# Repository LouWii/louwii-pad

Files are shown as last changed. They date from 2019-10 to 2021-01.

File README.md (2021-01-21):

# Louwii Pad

Very basic USB macro pad for tinkering and experimenting.

louwii-pad-rev1-small

## Bootloader Flashing

In case the ATmega32u4 comes without a bootloader flashed in, the board has an ICSP port to flash a bootloader. See [flashing an ATmega via ICSP on Sparkfun](https://learn.sparkfun.com/tutorials/installing-an-arduino-bootloader/all).

## Inspiration

* [ruiqimao's tutorial](https://github.com/ruiqimao/keyboard-pcb-guide)
* [Arisu](https://github.com/FateNozomi/arisu-pcb)
* [cpm43](https://github.com/Gtrx0/cpm43)
* [Gtrx0/Keyboard-template-atmega32u4](https://github.com/Gtrx0/Keyboard-template-atmega32u4)

[ATmega32u4 official doc](http://ww1.microchip.com/downloads/en/devicedoc/atmel-7766-8-bit-avr-atmega16u4-32u4_datasheet.pdf)

## BOM (list of components)

[See doc](BOM.md)

## Blank ATmega flashing (no bootloader flashed, fuses not set properly)

[See doc](ATMEGA.md)

## Firmware

[See doc](FIRMWARE.md)

## Revisions

[See doc](REVISIONS.md)

## Third party libs

[See doc](LIBS.md)

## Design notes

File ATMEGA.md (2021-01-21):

# ATmega flashing

Blank/virgin ATmega might be missing a few things in order to run properly as a macro pad with a QMK firmware.

## Setup

### ISP programmer and avrdude

The Louwii-pad exposes ISP pins of the ATmega in order to program it via an ISP programmer. You can use an Arduino as an ISP programmer ([see official doc](https://www.arduino.cc/en/tutorial/arduinoISP#toc2)), or buy a dedicated one like an USBasp ([see official page](https://www.fischl.de/usbasp/)).

There's no other way to program your ATmega32u4 if it came without a bootloader (in case of a Louwii-pad).

We're going to use the [avrdude](https://www.nongnu.org/avrdude/) command tool to set the fuses and flash the bootloader.

### ATmega Fuses

The fuses are used to set some parameters to the ATmega, defining how it runs. We need to set them according to our use.

* **Low:** 0xFF (we use an external 16Mhz resonator)
* **High:** 0xD9 (default flash size etc..., SPI enabled) -- Note: we could disable SPI once we're done, but it's nice to have them if we mess up
* **Extended:** 0xC0 (Brown-out set to 4.3V, Hardware boot enabled) -- Note: We might set the brown-out down to 3.5V, in case of a voltage drop: 0xC1

We're not touching the lock fuse, we don't need to. It should be set to 0xFF by default, allowing us to do anything we want.

[See more about fuses](https://eleccelerator.com/fusecalc/fusecalc.php?chip=atmega32u4&LOW=FF&HIGH=D9&EXTENDED=C0&LOCKBIT=FF)

### Bootloader

You can either use Atmel DFU bootloader or the QMK fork QMK DFU.

* [Atmel DFU link](https://www.microchip.com/wwwproducts/en/ATmega32U4#additional-features) - Go in the _Documents_ tab, scroll down to _Software Libraries/Firmware_ and download the bootloaders zip file. It contains `ATMega32U4-usbdevice_dfu-1_0_0.hex`, the bootloader ready to be flashed.
* [QMK DFU link](https://docs.qmk.fm/#/flashing?id=qmk-dfu) - QMK DFU contains some customizations compared to the Atmel DFU that cam be handy, but we're not using them really. It can be generated via `make` commands in the QMK repo: `make planck/rev4:default:bootloader`

## Steps

### 1. Check that the ATmega is detected

To see if your programmer detects the ATmega, run

```
sudo avrdude -c usbasp-clone -p m32u4
```

Remove `sudo` if you're running the command in Windows.

In my case, I'm using a usbasp clone (`usbasp-clone`). But you can change it to `usbasp` or `arduino` or any other programmer you use.

This should give you something like this

```
$ sudo avrdude -c usbasp-clone -p m32u4

avrdude: warning: cannot set sck period. please check for usbasp firmware update.
avrdude: AVR device initialized and ready to accept instructions

Reading | ################################################## | 100% 0.00s

avrdude: Device signature = 0x1e9587 (probably m32u4)

avrdude: safemode: Fuses OK (E:FF, H:D9, L:C0)

avrdude done.  Thank you.
```

If your fuses are different, that's fine, we're going to set them up properly.

### 2. Set the fuses

```
sudo avrdude -c usbasp-clone -p m32u4 -U lfuse:w:0xFF:m -U hfuse:w:0xD9:m -U efuse:w:0xC0:m
```

If you were not using the 16Mhz quartz yet, unplug the board and solder it in, the ATmega is now set to use it.

### 3. Flash the bootloader

```
sudo avrdude -c usbasp-clone -p m32u4 -U flash:w:ATMega32U4-usbdevice_dfu-1_0_0.hex
```

Once the bootloader is flashed, the ATmega will boot up in bootloader mode, ready to flash a program on it.

## The external resonator problem

```
device signature = 0x000000
device signature always changing
avrdude: initialization failed, rc=-1
```

When I received my ATmega chips, the fuses were set in such a way that the ATmega was expecting a "low speed" external resonator to be set on the XTAL1 pin. That's a hard to track problem: the ATmega wasn't responding when trying to be contacted via the SPI pins, and there's no way to know or change the fuses. After many hours of research, trial and error, I found 1 solution that worked: generating an approximate 8Mhz square wave signal via an Arduino.

What I did was: removing the 16Mhz quartz from the PCB. Connect the pin 9 or my Arduino Leonardo to the XTAL1 pin of the ATmega32u4 (the one on the left side on X1). Power on the Arduino. Connect the ATmega to the programmer. Run the test command, cross fingers. And the ATmega showed up.

The arduino program:

```
#ifdef __AVR_ATmega2560__
  const byte CLOCKOUT = 11;  // Mega 2560
#else
  const byte CLOCKOUT = 9;   // Uno, Duemilanove, etc.
#endif

void setup ()
{
  // set up 8 MHz timer on CLOCKOUT (OC1A)
  pinMode (CLOCKOUT, OUTPUT);
  // set up Timer 1
  TCCR1A = bit (COM1A0);  // toggle OC1A on Compare Match
  TCCR1B = bit (WGM12) | bit (CS10);   // CTC, no prescaling
  OCR1A =  0;       // output every cycle
}

void loop ()
{
  // whatever
}
```

The ATmega can also use its internal clock, so depending on how its fuses were set (specifically the `LOW` fuse), it might be able to respond to the avrdude command without any resonator soldered in. Boy, this ain't easy.

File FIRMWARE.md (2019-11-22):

# Firmware

I'm using [QMK](https://qmk.fm/), it's a keyboard firmware framework but has a ton of features, making it super easy to implement features for louwii-pad, including OLED screen, rotary encoders, RGB lights etc...

The firmware is in a separate repository: [LouWii/qmk_firmware](https://github.com/LouWii/qmk_firmware/tree/louwii-pad), branch `louwii-pad`

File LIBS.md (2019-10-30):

# Libs & other third party elements

Rotary encoder 3D model from [Alps](https://www.alps.com/prod/info/E/HTML/Encoder/Incremental/EC11/EC11_list.html). Modified  in FreeCAD because that pink color was hurting my eyes.

OLED screen 3D model from [GrabCAD](https://grabcad.com/library/oled-display-128x32-1)

Took a few footprints from [keyboard_parts.pretty](https://github.com/colemarkham/keyboard_parts.pretty)

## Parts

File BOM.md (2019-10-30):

# BOM (components list)

I tried to use widely available components to make it as affordable as possible and accessible. No fancy connector made by 1 manufacturer only (well, the only exception to this is the ATmega32u4, but it's one of the best chip for this use, I don't think it's going to be ended soon). That hopefully means we should still be able to find the components in years to come.

| ref | components | quantity | packaging | notes | links |
| --- | --- | --- | --- | --- | --- |
| U1 | ATmega32u4 | 1 | TQFP44 | sometimes called ATmega32u4-AU | [LCSC](https://lcsc.com/product-detail/ATMEL-AVR_ATMEL_ATMEGA32U4-AU_ATMEGA32U4-AU_C44854.html) |
| X1 | Crystal 16Mhz | 1 | HC49-US | 20ppm or 30ppm | [LCSC](https://lcsc.com/product-detail/DIP-Crystal-Resonators_Yangxing-Tech-X49SD16MSD2SC_C16212.html) |
| SW1 | Tactile switch 5.2x5.2mm | 1 | | SMD switch | [LCSC](https://lcsc.com/product-detail/Tactile-Switches_Korean-Hroparts-Elec-K2-1187SQ-D4SW-06_C223821.html) |
| J1 | Mini USB B connector | 1 | | | [LCSC](https://lcsc.com/product-detail/USB-Connectors_Jing-Extension-of-the-Electronic-Co-C69074_C69074.html) |
| J2 | 2x3 header pin | 1 | | 2.54mm pitch; optional component | [LCSC](https://lcsc.com/product-detail/Pin-Header-Female-Header_Boom-Precision-Elec-C65114_C65114.html) |
| RSW1 | rotary encoder switch | 1 | EC11E or EC12E | With momentary switch built-in | |
| RSW2 - 6 | rotary encoder | 5 | EC11E or EC12E | | |
| RGB1 - 4 | WS2812B | 4 | | RGB LED SMD | [LCSC](https://lcsc.com/product-detail/Light-Emitting-Diodes-LED_Worldsemi-WS2812B-B_C114586.html) |
| D1 - 8 | diode 1N4148 | 8 | DO-35 | | [LCSC](https://lcsc.com/product-detail/Switching-Diode_Semtech-1N4148_C14516.html) |
| R1, R2 | resistor 10k | 2 | DIN0204 or DIN 0207 | 1/4W or 1/6W, metal film | [LCSC](https://lcsc.com/product-detail/Metal-Film-Resistor-TH_TA-I-Tech-RN16T21002F_C172508.html) |
| R3, R4 | resistor 22 | 2 | DIN0204 or DIN 0207 | 1/4W or 1/6W, metal film | [LCSC](https://lcsc.com/product-detail/Metal-Film-Resistor-TH_Chian-Chia-Elec-MF1-4W-22%CE%A9-1-T52_C119288.html) |
| R5, R6 | resistor 4.7k | 2 | DIN0204 or DIN 0207 | 1/4W or 1/6W, metal film | [LCSC](https://lcsc.com/product-detail/Metal-Film-Resistor-TH_Uniroyal-Elec-MFR0W4F4701A50_C57204.html) |
| C1, C2 | capacitor 22pF | 2 | ceramic leaded | 10%, 5mm pitch for cheapest | [LCSC](https://lcsc.com/product-detail/Multilayer-Ceramic-Capacitors-MLCC-Leaded_Dersonic-CD1H220JC9BECHD000_C263190.html) |
| C3 | capacitor 1uF | 1 | ceramic leaded | 10%, 5mm pitch for cheapest | [LCSC](https://lcsc.com/product-detail/Multilayer-Ceramic-Capacitors-MLCC-Leaded_Dersonic-CD1H105KC9IER1E000_C263187.html) |
| C4 - C7  | capacitor 0.1uF | 4 | ceramic leaded | (=100nF), 10%, 5mm pitch for cheapest | [LCSC](https://lcsc.com/product-detail/Multilayer-Ceramic-Capacitors-MLCC-Leaded_Dersonic-CD1H104KC94ER1E000_C263182.html) |
| C8 | capacitor 4.7uF | 1 | radial leaded | lead spacing 2mm | [LCSC](https://lcsc.com/product-detail/Aluminum-Electrolytic-Capacitors-Leaded_Rubycon-50YXF4R7MEFC5X11_C88759.html) |
| K1 - 8 | mechanical switch | 8 | | MX cherry compatible mechanical keyboard switches | |

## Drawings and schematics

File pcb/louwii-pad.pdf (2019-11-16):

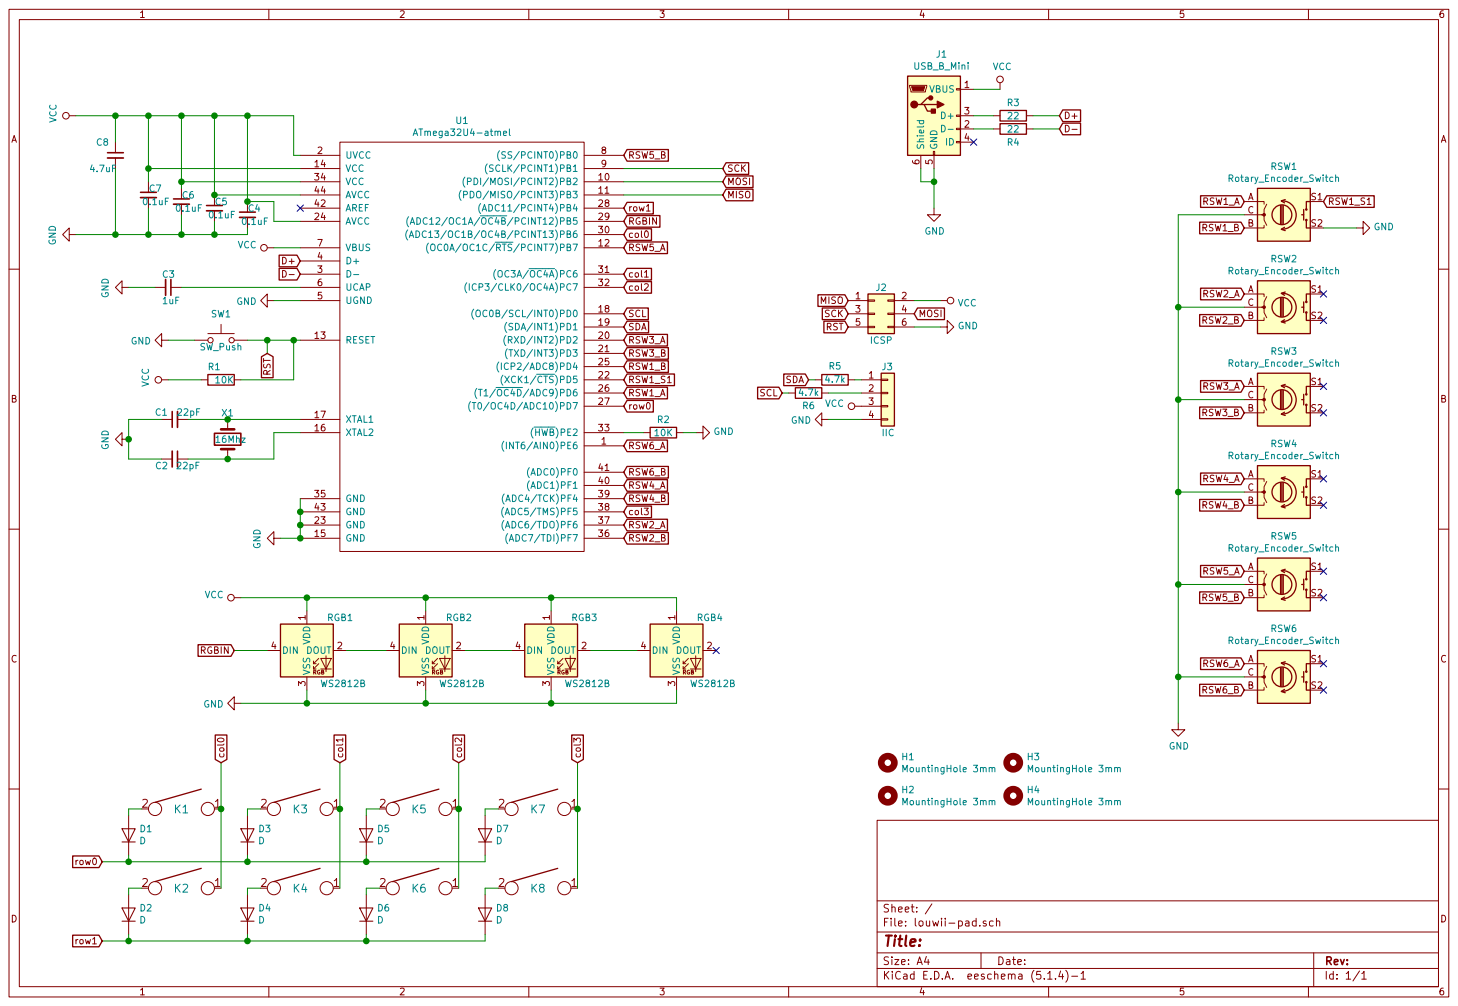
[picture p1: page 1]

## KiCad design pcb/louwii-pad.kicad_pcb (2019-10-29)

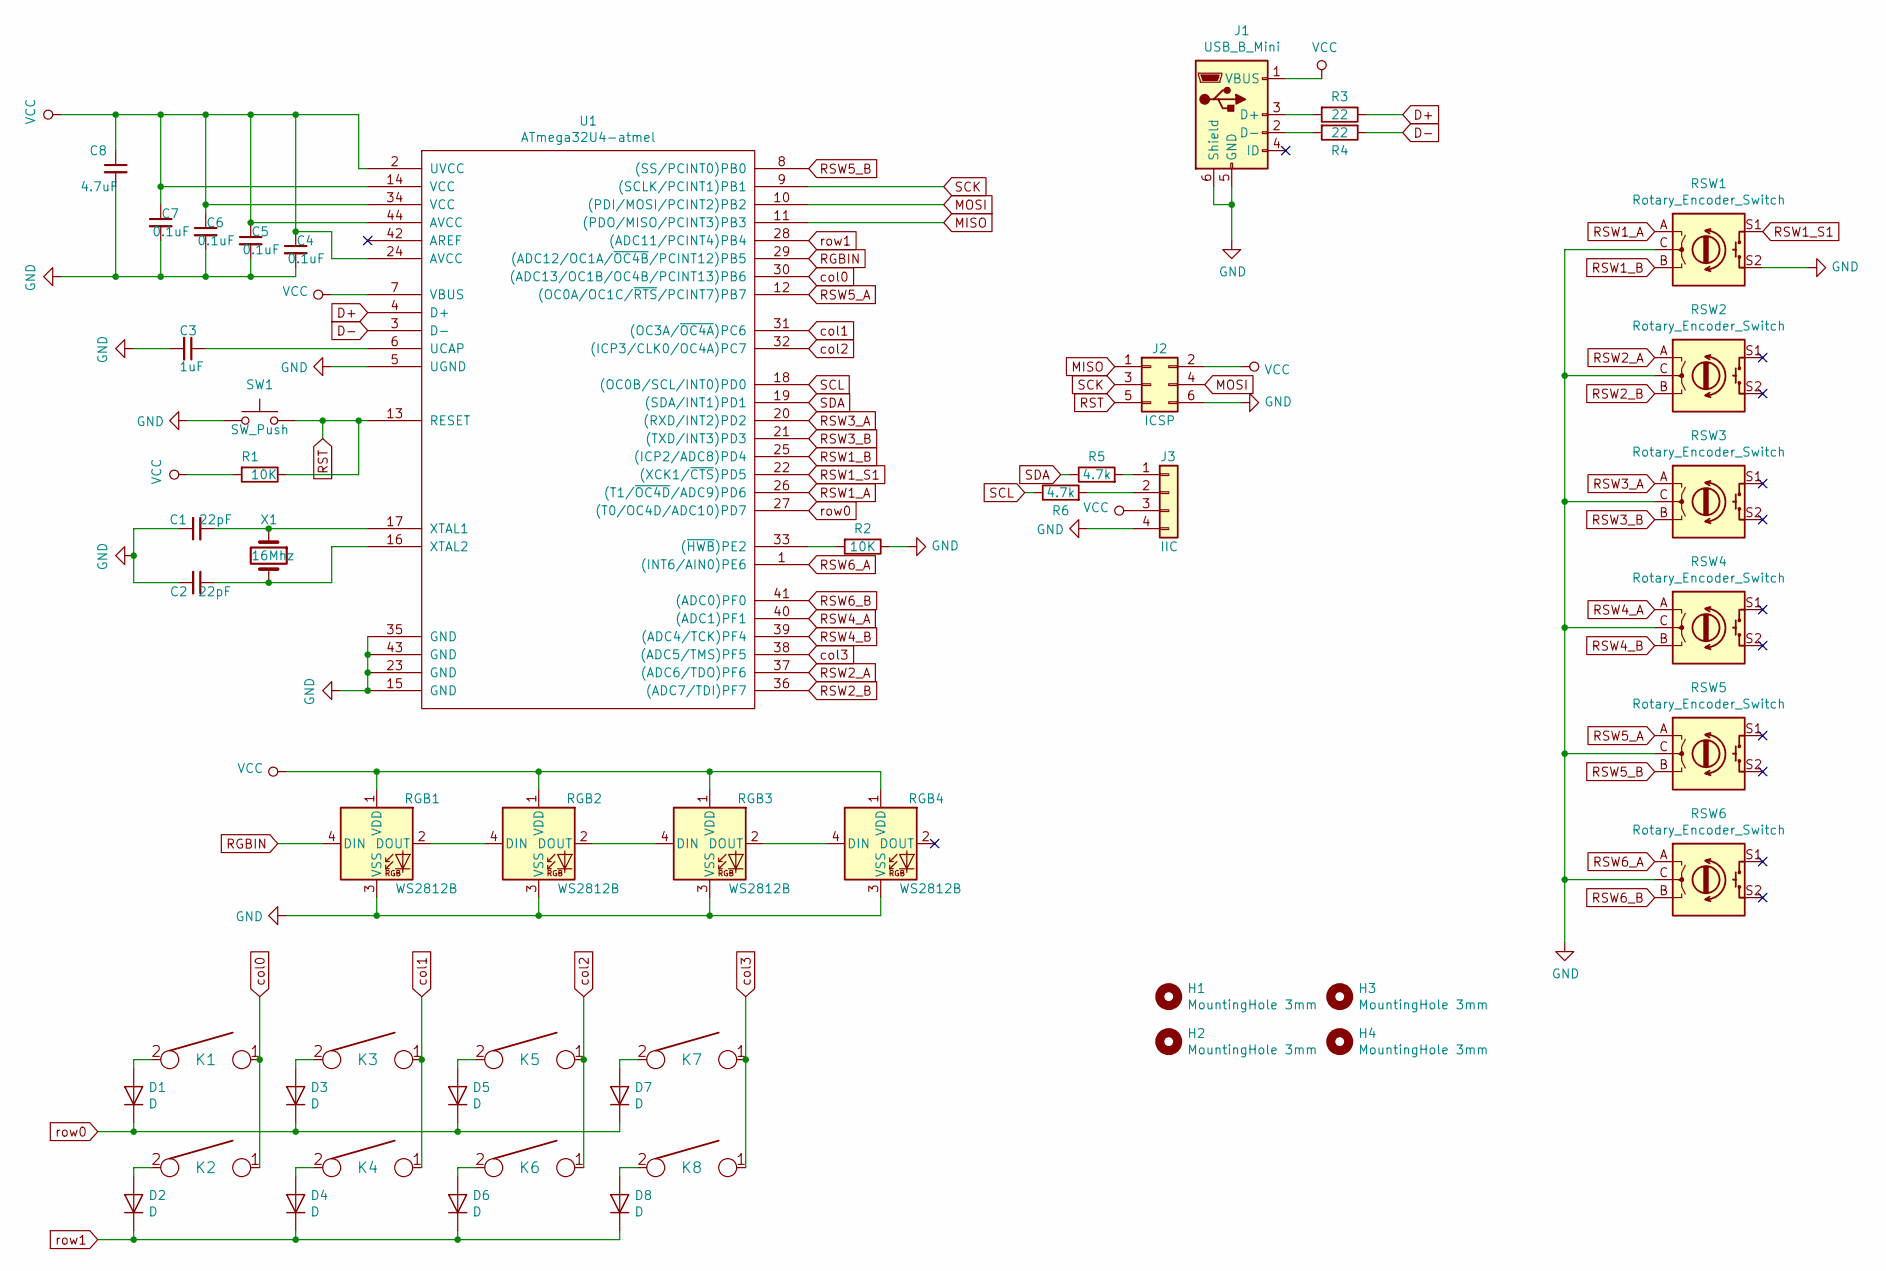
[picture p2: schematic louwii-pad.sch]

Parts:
C1, C2: 22pF; C_Disc_D4.3mm_W1.9mm_P5.00mm
C3: 1uF; C_Disc_D4.3mm_W1.9mm_P5.00mm
C4, C5, C6, C7: 0.1uF; C_Disc_D4.3mm_W1.9mm_P5.00mm
C8: 4.7uF; C_Radial_D5.0mm_H7.0mm_P2.00mm
D1, D2, D3, D4, D5, D6, D7, D8: D; D_DO-35_SOD27_P7.62mm_Horizontal
H1, H2, H3, H4: MountingHole 3mm; MountingHole_3.2mm_M3_ISO7380_Pad
J1: USB_B_Mini; USB_Mini-B_Lumberg_2486_01_Horizontal
J2: ICSP; PinHeader_2x03_P2.54mm_Vertical
J3: IIC; PinHeader_1x04_P2.54mm_Vertical
K1, K2, K3, K4, K5, K6, K7, K8: KEYSW; MX_PCB_100H
R1, R2: 10K; R_Axial_DIN0207_L6.3mm_D2.5mm_P10.16mm_Horizontal
R3, R4: 22; R_Axial_DIN0207_L6.3mm_D2.5mm_P10.16mm_Horizontal
R5, R6: 4.7k; R_Axial_DIN0207_L6.3mm_D2.5mm_P10.16mm_Horizontal
RGB1, RGB2, RGB3, RGB4: WS2812B; WS2812b
RSW1, RSW2, RSW3, RSW4, RSW5, RSW6: Rotary_Encoder_Switch; RotaryEncoder_Alps_EC11E-Switch_Vertical_H20mm
SW1: SW_Push; SW_SPST_TL3342
U1: ATmega32U4-atmel; TQFP-44_10x10mm_P0.8mm
X1: 16Mhz; Crystal_HC49-U_Vertical

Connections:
D+: R3.1, U1.4 (D+)
D-: R4.1, U1.3 (D-)
GND: C1.1, C2.2, C3.2, C4.2, C5.2, C6.2, C7.2, C8.2, J1.5 (GND), J1.6 (Shield), J2.6, J3.4, R2.1, RGB1.3 (VSS), RGB2.3 (VSS), RGB3.3 (VSS), RGB4.3 (VSS), RSW1.C, RSW1.S2, RSW2.C, RSW3.C, RSW4.C, RSW5.C, RSW6.C, SW1.1, U1.5 (UGND), U1.15 (GND), U1.23 (GND), U1.35 (GND), U1.43 (GND)
MISO: J2.1, U1.11 ((PDO/MISO/PCINT3)PB3)
MOSI: J2.4, U1.10 ((PDI/MOSI/PCINT2)PB2)
unnamed: C1.2, U1.17 (XTAL1), X1.1
unnamed: C2.1, U1.16 (XTAL2), X1.2
unnamed: C3.1, U1.6 (UCAP)
unnamed: D1.2 (A), K1.2
unnamed: D2.2 (A), K2.2
unnamed: D3.2 (A), K3.2
unnamed: D4.2 (A), K4.2
unnamed: D5.2 (A), K5.2
unnamed: D6.2 (A), K6.2
unnamed: D7.2 (A), K7.2
unnamed: D8.2 (A), K8.2
unnamed: J1.2 (D-), R4.2
unnamed: J1.3 (D+), R3.2
unnamed: J3.1, R5.2
unnamed: J3.2, R6.2
unnamed: R2.2, U1.33 ((~HWB~)PE2)
unnamed: RGB1.2 (DOUT), RGB2.4 (DIN)
unnamed: RGB2.2 (DOUT), RGB3.4 (DIN)
unnamed: RGB3.2 (DOUT), RGB4.4 (DIN)
RGBIN: RGB1.4 (DIN), U1.29 ((ADC12/OC1A/~OC4B~/PCINT12)PB5)
RST: J2.5, R1.1, SW1.2, U1.13 (RESET)
RSW1_A: RSW1.A, U1.26 ((T1/~OC4D~/ADC9)PD6)
RSW1_B: RSW1.B, U1.25 ((ICP2/ADC8)PD4)
RSW1_S1: RSW1.S1, U1.22 ((XCK1/~CTS~)PD5)
RSW2_A: RSW2.A, U1.37 ((ADC6/TDO)PF6)
RSW2_B: RSW2.B, U1.36 ((ADC7/TDI)PF7)
RSW3_A: RSW3.A, U1.20 ((RXD/INT2)PD2)
RSW3_B: RSW3.B, U1.21 ((TXD/INT3)PD3)
RSW4_A: RSW4.A, U1.40 ((ADC1)PF1)
RSW4_B: RSW4.B, U1.39 ((ADC4/TCK)PF4)
RSW5_A: RSW5.A, U1.12 ((OC0A/OC1C/~RTS~/PCINT7)PB7)
RSW5_B: RSW5.B, U1.8 ((SS/PCINT0)PB0)
RSW6_A: RSW6.A, U1.1 ((INT6/AIN0)PE6)
RSW6_B: RSW6.B, U1.41 ((ADC0)PF0)
SCK: J2.3, U1.9 ((SCLK/PCINT1)PB1)
SCL: R6.1, U1.18 ((OC0B/SCL/INT0)PD0)
SDA: R5.1, U1.19 ((SDA/INT1)PD1)
VCC: C4.1, C5.1, C6.1, C7.1, C8.1, J1.1 (VBUS), J2.2, J3.3, R1.2, RGB1.1 (VDD), RGB2.1 (VDD), RGB3.1 (VDD), RGB4.1 (VDD), U1.2 (UVCC), U1.7 (VBUS), U1.14 (VCC), U1.24 (AVCC), U1.34 (VCC), U1.44 (AVCC)
col0: K1.1, K2.1, U1.30 ((ADC13/OC1B/OC4B/PCINT13)PB6)
col1: K3.1, K4.1, U1.31 ((OC3A/~OC4A~)PC6)
col2: K5.1, K6.1, U1.32 ((ICP3/CLK0/OC4A)PC7)
col3: K7.1, K8.1, U1.38 ((ADC5/TMS)PF5)
row0: D1.1 (K), D3.1 (K), D5.1 (K), D7.1 (K), U1.27 ((T0/OC4D/ADC10)PD7)
row1: D2.1 (K), D4.1 (K), D6.1 (K), D8.1 (K), U1.28 ((ADC11/PCINT4)PB4)

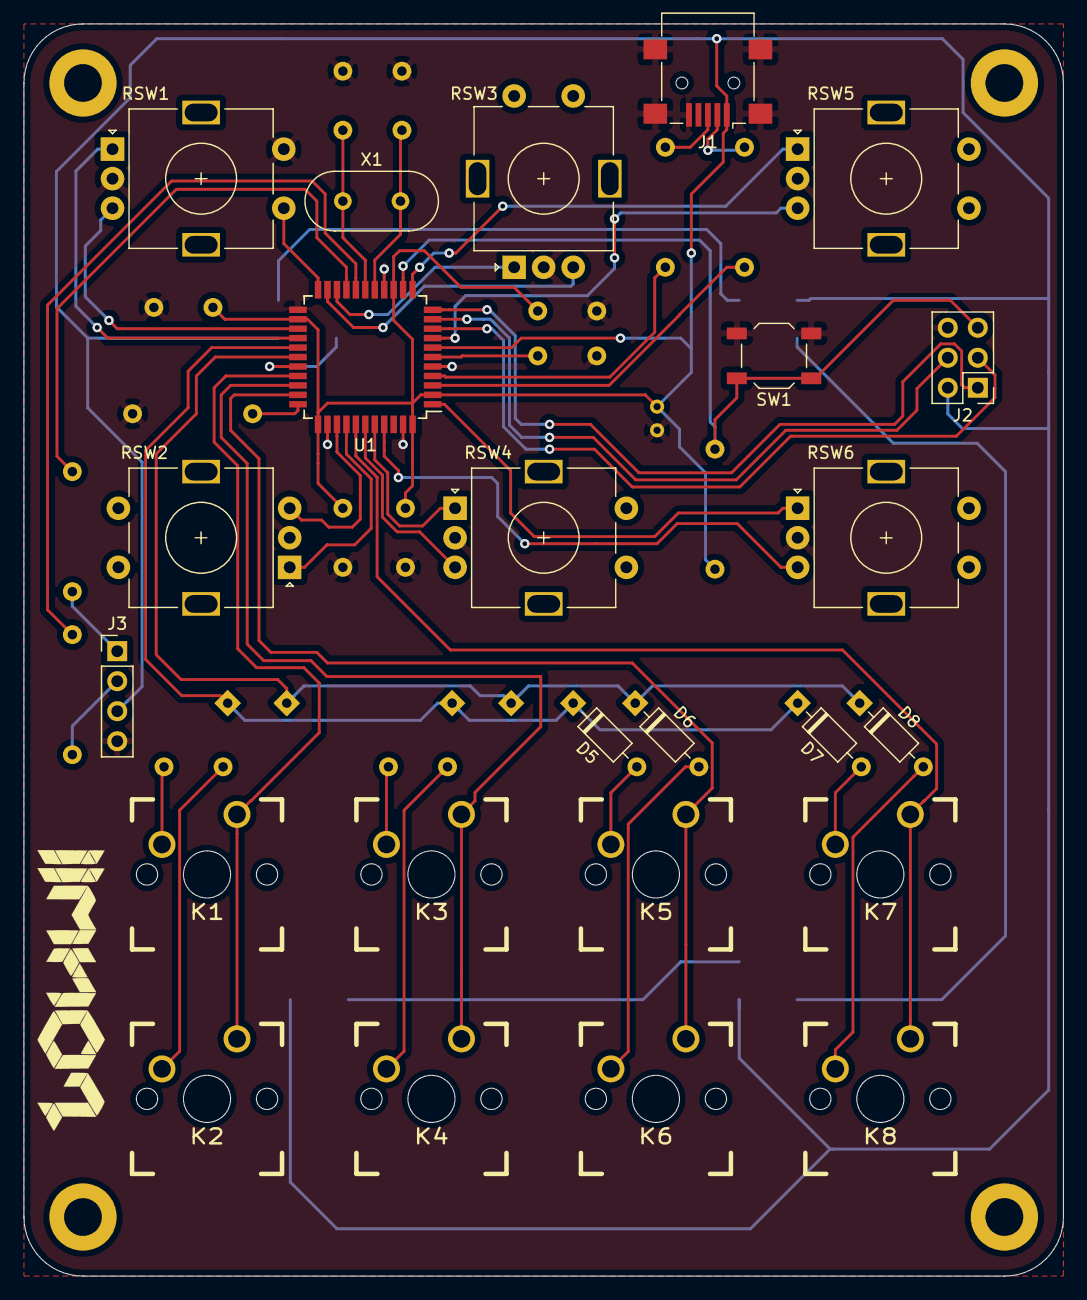
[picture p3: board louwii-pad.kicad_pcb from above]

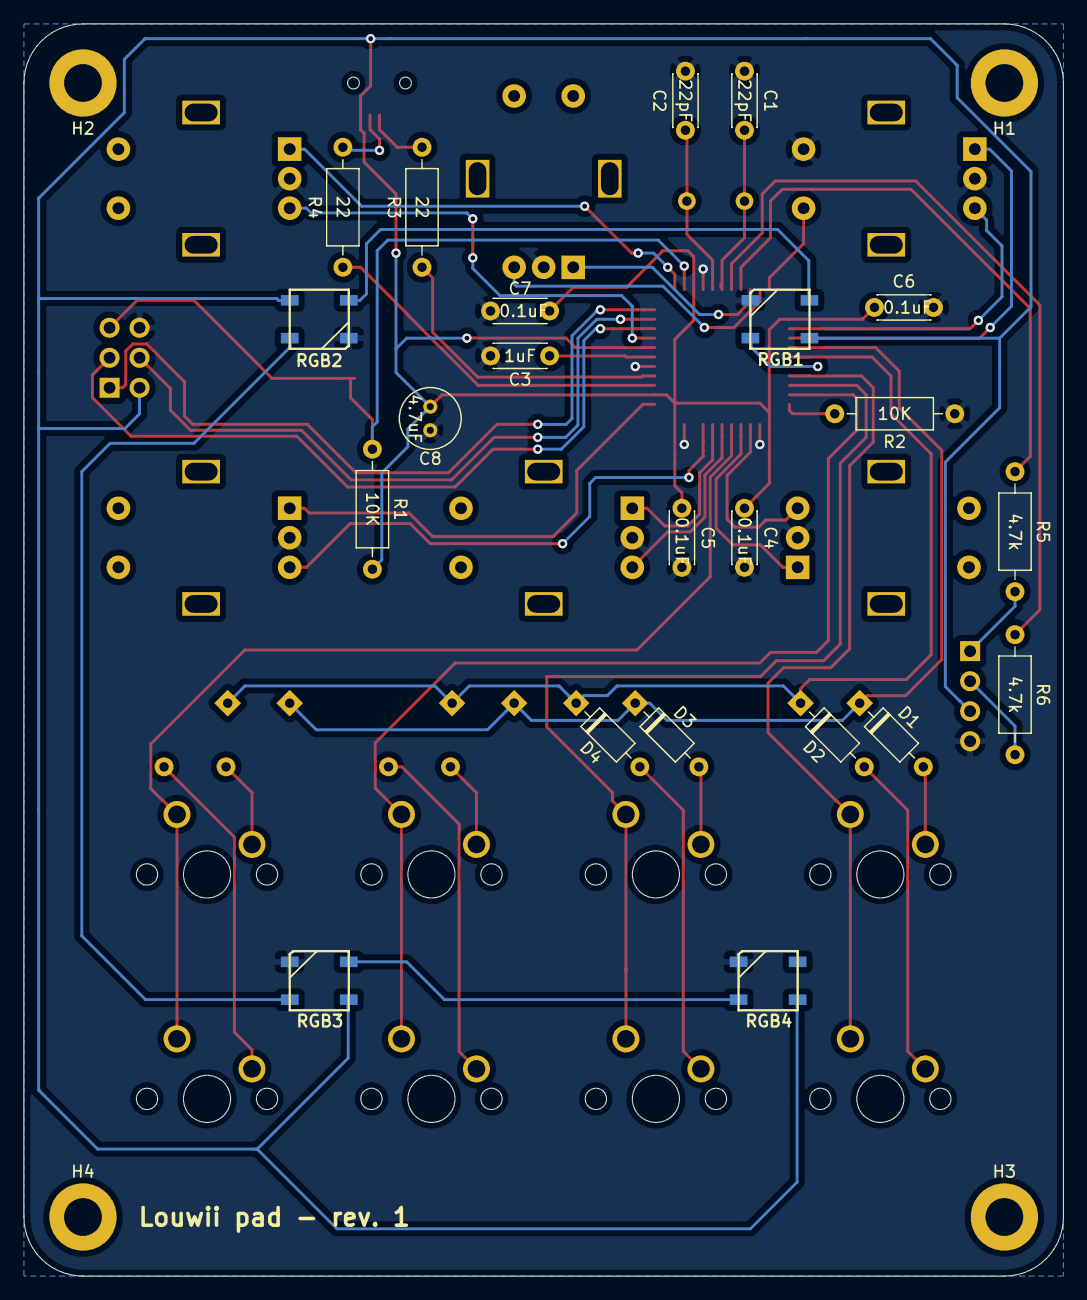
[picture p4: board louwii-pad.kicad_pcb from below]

Board: 2 copper layers, 88.0 x 106.0 mm, 50 parts (22 on the bottom side), 49 nets.

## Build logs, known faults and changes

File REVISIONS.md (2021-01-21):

 
# Revisions

## Revision 1

First rev made. Got PCBs manufactured by JLCPCB for cheap.

Everything is working ok, not issues in the wiring, which is good. The ATmega32u4 is not easy to solder, but I was expecting that. It's doable though, with some patience and some [flux](https://en.wikipedia.org/wiki/Flux_(metallurgy)).

However, there are a few points that can be improved:

* The OLED screen placement is not the best. Might be better to put it between the rotary encoder rows. Or increase the spacing between the encoders and the switches.
* The mini-usb socket soldering is not easy. If not done right, it causes disconnections and other problems. The way it's supposed to be attached is not great either, and the socket can be ripped off easily. The socket that I got adds even more issues. The cable wiggles a lot when plugged in, also causing random disconnections. **Lots of issues for a single part.** I would probably change it for a micro-usb through-hole socket, which would be sturdier and easier to solder. I like mini-USB, I find it less fragile that micro-usb, and never really had issues with it before (a lot of specialized mechanical keyboards still them), that's why I chose that in the first place. The best would be a USB C port, but it requires some extra components. And we need to find an easy one to solder. SMD is not gonna do it, not after the mess I went through with the SMD mini USB.
* Flash space on the ATmega32u4 is a bit small when using QMK firmware with all the features enabled (well, features that we need). I know some keyboards use an ATmega328p which is available in a DIP format (easier to solder), I wonder if we could use a 644 (or 644P). Might be worth digging.

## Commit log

2019-10-24 add WIP pcb schematics
    [louwii-pad.kicad_pcb, louwii-pad.sch]
2019-10-24 add RGB leds - WIP
    [louwii-pad.sch]
2019-10-25 Finished PCB schematics
    [louwii-pad.sch]
2019-10-25 fix component ids
    [louwii-pad.sch]
2019-10-25 finish up schematics and start PCB design
    [louwii-pad.sch]
2019-10-26 add BOM
2019-10-26 update schematics, update net, update footprints, update pcb design with missing footprints
    [louwii-pad.kicad_pcb, louwii-pad.sch]
2019-10-27 add more 3d models, finish up PCB tracing
    [louwii-pad.kicad_pcb, louwii-pad.sch]
2019-10-28 finish up tracing, updating footprints, adding 3d models
    [louwii-pad.kicad_pcb, louwii-pad.sch]
2019-10-28 cleanup silk layers
    [louwii-pad.kicad_pcb]
2019-10-29 add logo and rev on PCB
    [louwii-pad.kicad_pcb]
2019-10-29 add gerber files
    [louwii-pad-B_Cu.gbl, louwii-pad-B_Mask.gbs, louwii-pad-B_Paste.gbp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]
2026-10-10 Update all documentation, insert new images and demo
